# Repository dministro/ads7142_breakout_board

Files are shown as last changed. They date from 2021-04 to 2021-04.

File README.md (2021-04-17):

# ADS7142 breakout board (A003.0000017200_DM.ADS7142.BOB)

This is a simple breakout board for
 Texas Instruments ADS7142 (X2QFN) dual-channel, programmable sensor monitor.

[0] - Datasheet: https://www.ti.com/lit/ds/symlink/ads7142.pdf

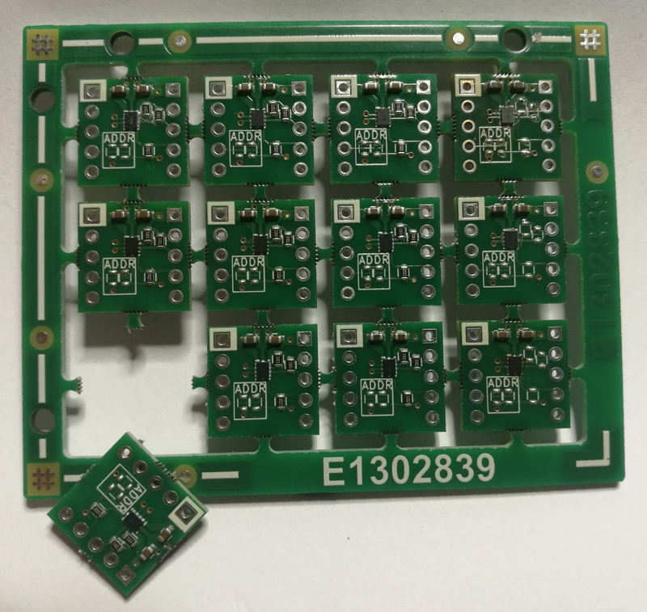
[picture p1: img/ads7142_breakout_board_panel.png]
ADS7142 breakout board


## Pinout

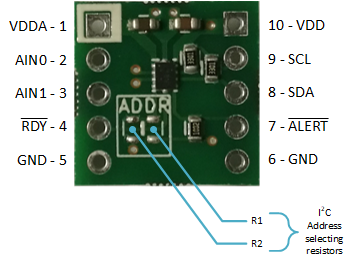
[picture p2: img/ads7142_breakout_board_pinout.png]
ADS7142 breakout board pinout


|# |Function  |Description |
|-----|---|---|
|1 |VDDA |Analog supply input. See AVDD in ref [0] |
|2 |AIN0 |Channel 0 analog signal input, or positive analog signal input. See AINP/AIN0 in ref [0] |
|3 |AIN1 |Channel 1 analog signal input, or negative analog signal input. See AINM/AIN1 in ref [0] |
|4 |RDY |See BUSY/RDY in ref [0] |
|5 |GND |Ground for power supply |
|6 |GND |Ground for power supply |
|7 |ALERT |See ALERT in ref [0] |
|8 |SDA |Serial data in/out. See SDA in ref [0] |
|9 |SCL |Serial clock. See SCL in ref [0] |
|10 |VDD |Digital I/O supply voltage. See DVDD in ref [0]  |

## Configuration

To select the device address on I2C bus, populate the proper resistor values (R1, R2) as described in the datasheet. See chapter *7.3.6 I2C Address Selector* in [0]

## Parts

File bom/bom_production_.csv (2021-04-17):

Component | Description | Part | References | Value | Footprint | Quantity Per PCB | Manufacturer | PartNumber | Distributor#1 | OrderingCode#1 | Distributor#2 | OrderingCode#2 | InsertManufacturer | InsertProductCode | InsertDistributor#1 | InsertOrderingCode#1 | MateManufacturer | MateProductCode | MateDistributor#1 | MateOrderingCode#1 | ExtraTool#1Manufacturer | ExtraTool#1ProductCode | ExtraTool#1Distributor#1 | ExtraTool#1OrderingCode#1 | Datasheet | Layer
1 | Unpolarized capacitor | C | C1003 C1004 | 1u / X7R / 16V | C_0603 | 2 | KEMET | C0603C105K4RACTU | www.mouser.com | 80-C0603C105K4R |  |  |  |  |  |  |  |  |  |  |  |  |  |  | ~ | F.Cu
2 | Unpolarized capacitor | C | C1001 C1002 | 470p / X7R / 16V | C_0402 | 2 | KEMET | C0402C471K4RACTU | www.mouser.com | 80-C0402C471K4R |  |  |  |  |  |  |  |  |  |  |  |  |  |  | ~ | B.Cu
3 | Generic connector, single row, 01x05, script generated (kicad-library-utils/schlib/autogen/connector/) | Conn_01x05_Male | J1001 J1002 | Conn_01x05_Male | Pin_Header_Straight_1x05_Pitch2.54mm | 2 | Amphenol FCI | 77311-118-05LF | www.mouser.com | 649-77311-118-05LF |  |  |  |  |  |  |  |  |  |  |  |  |  |  | ~ | B.Cu
4 | Resistor | R | R1005 | 10k / 1% | R_0603 | 1 | Vishay / Dale | CRCW060310K0FKEAC | www.mouser.com | 71-CRCW060310K0FKEAC |  |  |  |  |  |  |  |  |  |  |  |  |  |  | ~ | F.Cu
5 | Resistor | R | R1001 R1002 | 1k / 1% | R_0402 | 2 | Vishay / Dale | CRCW04021K00FKEDC | www.mouser.com | 71-CRCW04021K00FKEDC |  |  |  |  |  |  |  |  |  |  |  |  |  |  | ~ | B.Cu
6 | Resistor | R | R1003 R1004 | 3.3k / 1% | R_0603 | 2 | Vishay / Dale | CRCW06033K30FKEAC | www.mouser.com | 71-CRCW06033K30FKEAC |  |  |  |  |  |  |  |  |  |  |  |  |  |  | ~ | F.Cu
7 | Resistor | R | R1006 R1007 | DNP | R_0603 | 2 |  |  |  |  |  |  |  |  |  |  |  |  |  |  |  |  |  |  | ~ | F.Cu
8 | Nanopower, Dual-Channel, Programmable Sensor Monitor | ADS7142 | U1001 | ADS7142 | Texas_RUG0010A_X2QFN-10_1.5x2mm_Pitch0.5mm | 1 | Texas Instruments | ADS7142IRUGT | www.mouser.com | 595-ADS7142IRUGT |  |  |  |  |  |  |  |  |  |  |  |  |  |  | https://www.ti.com/lit/ds/symlink/ads7142.pdf | F.Cu
Component Groups: | 8
Component Count: | 14
Fitted Components: | 14
Number of PCBs: | 1
Total components: | 14
Schematic Version:
Schematic Date:
BoM Date: | 17/04/2021 10:51:19
Schematic Source: | D:\Projects\DM.ADS7142.BOB\cad\eda\A003.0000017200_DM.ADS7142.BOB\A003.0000017200_DM.ADS7142.BOB.sch
KiCad Version: | Eeschema (5.1.6-14-g3ac0951e1-dirty)

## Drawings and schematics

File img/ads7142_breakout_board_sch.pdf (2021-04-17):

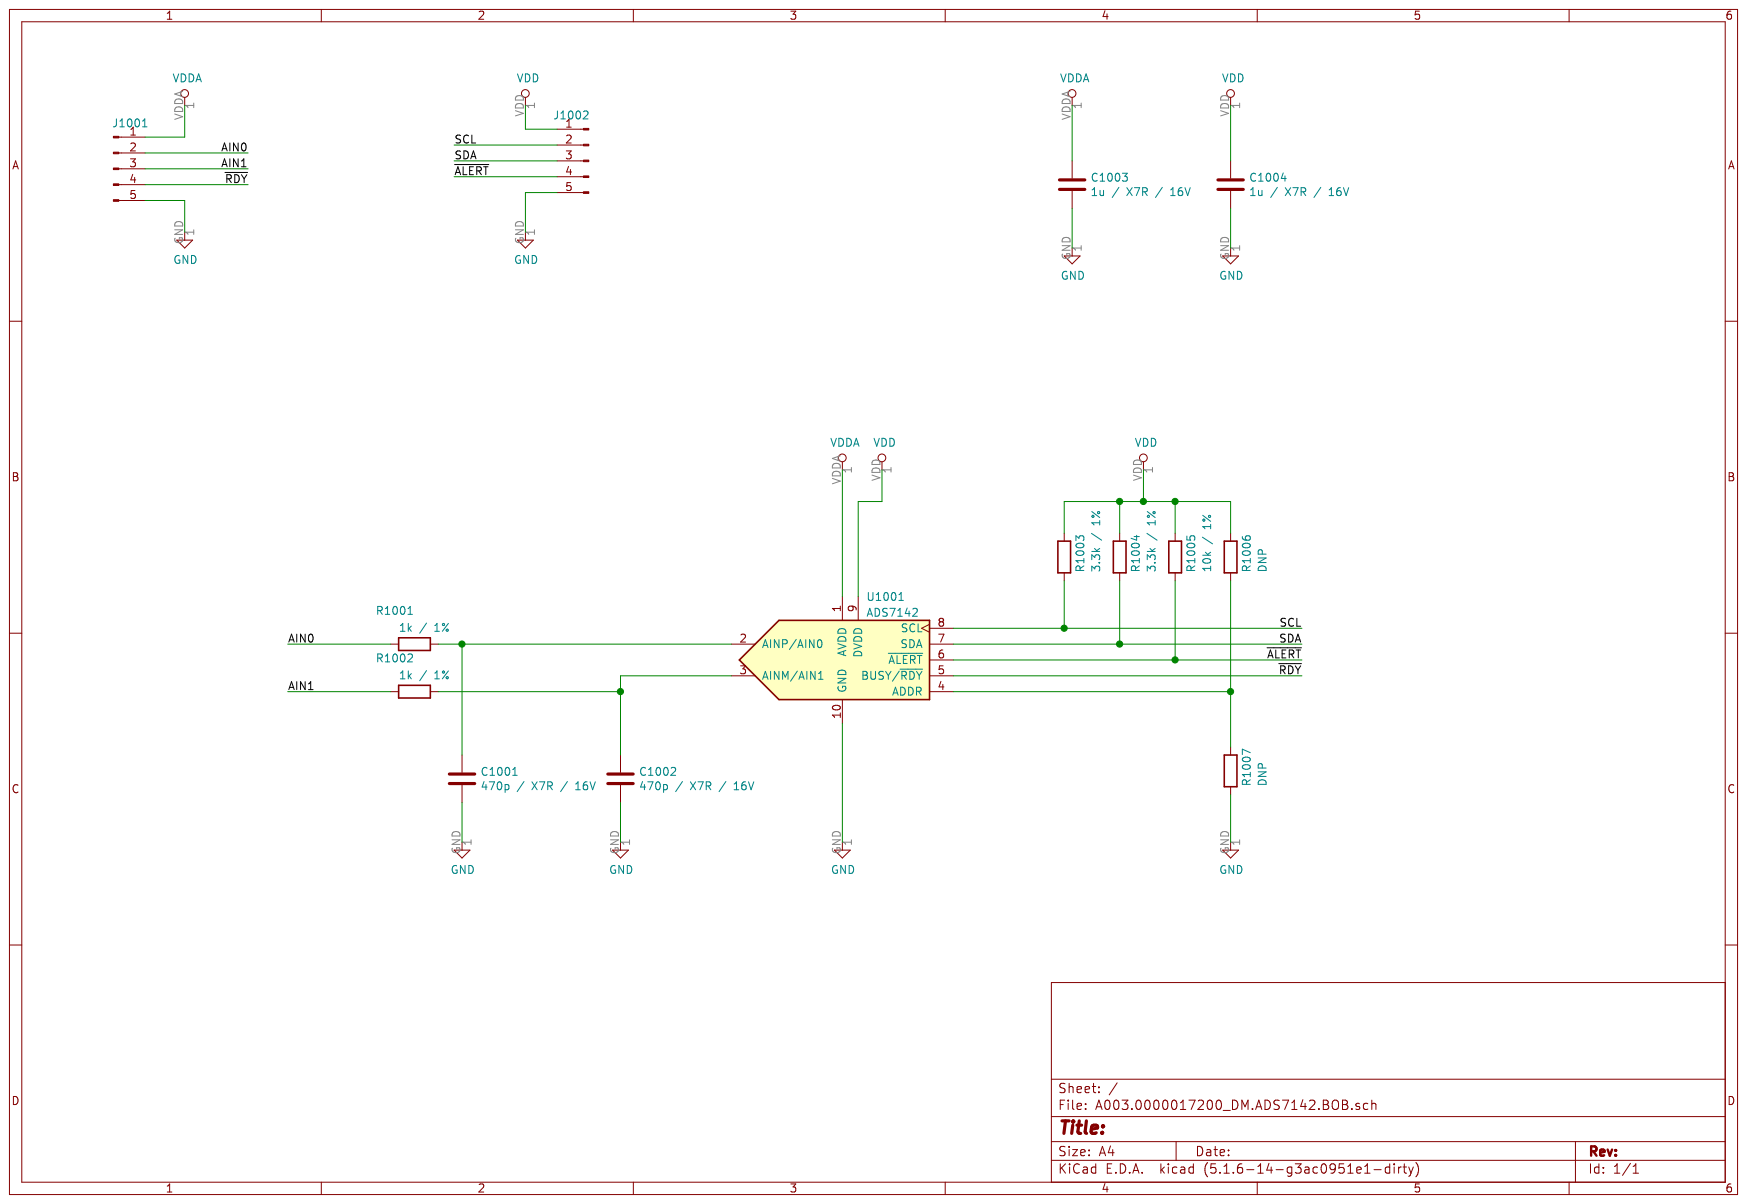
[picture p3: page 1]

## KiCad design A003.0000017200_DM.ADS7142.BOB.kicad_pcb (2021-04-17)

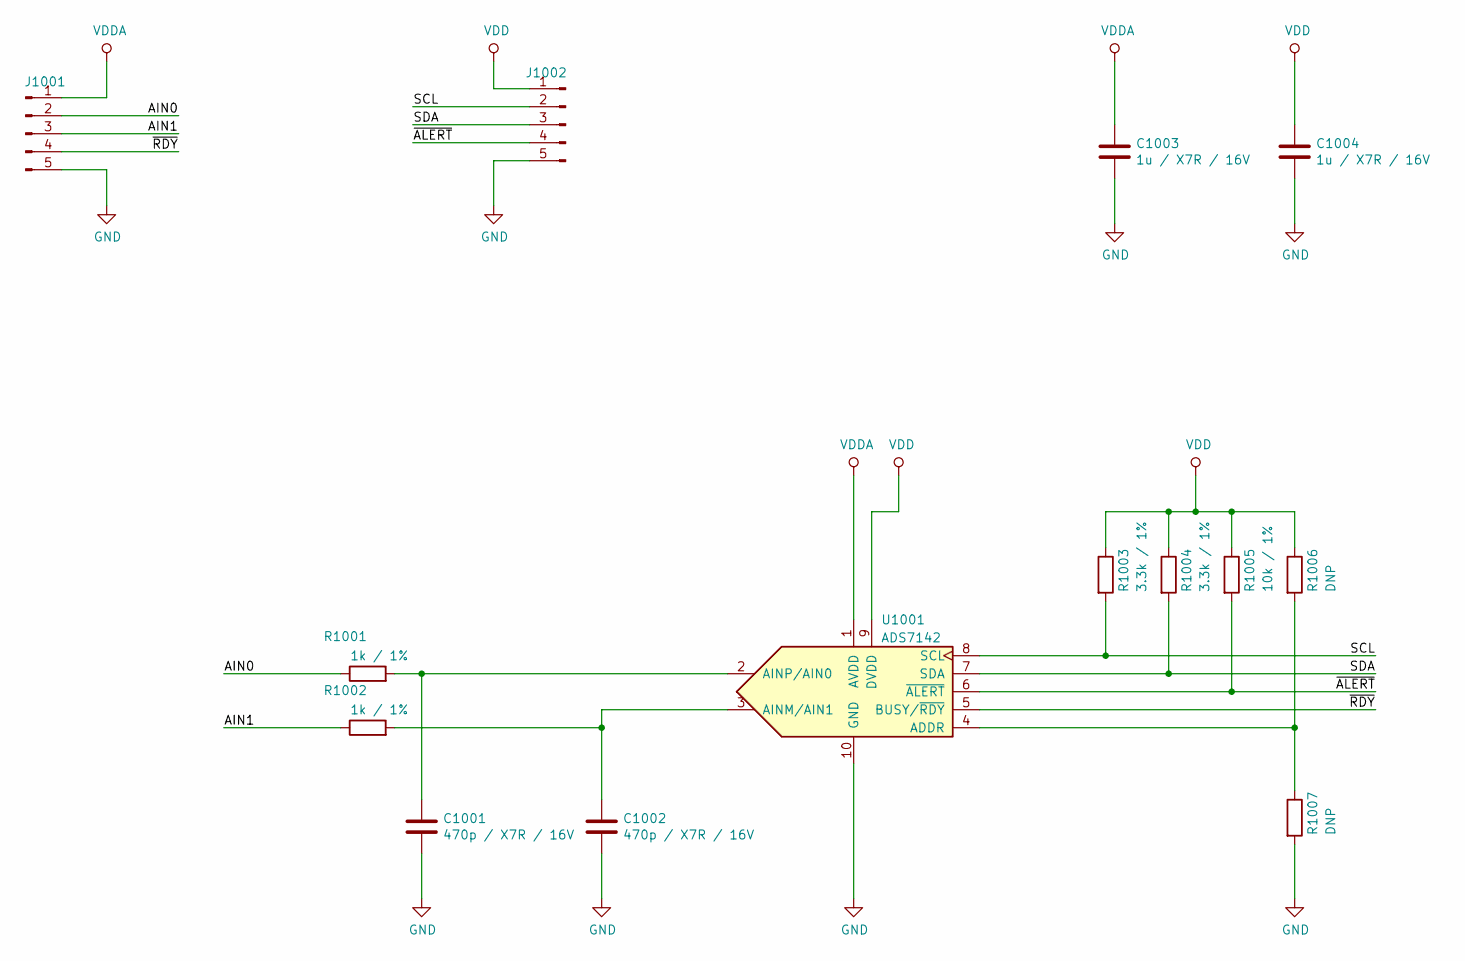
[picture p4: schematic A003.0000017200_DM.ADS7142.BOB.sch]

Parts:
C1001, C1002: 470p / X7R / 16V; C_0402; PartNumber C0402C471K4RACTU
C1003, C1004: 1u / X7R / 16V; C_0603; PartNumber C0603C105K4RACTU
J1001, J1002: Conn_01x05_Male; Pin_Header_Straight_1x05_Pitch2.54mm; PartNumber 77311-118-05LF
R1001, R1002: 1k / 1%; R_0402; PartNumber CRCW04021K00FKEDC
R1003, R1004: 3.3k / 1%; R_0603; PartNumber CRCW06033K30FKEAC
R1005: 10k / 1%; R_0603; PartNumber CRCW060310K0FKEAC
R1006, R1007: DNP; R_0603
U1001: ADS7142; Texas_RUG0010A_X2QFN-10_1.5x2mm_Pitch0.5mm; PartNumber ADS7142IRUGT

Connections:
/AIN0: J1001.2, R1001.1
/AIN1: J1001.3, R1002.1
/SCL: J1002.2, R1003.2, U1001.8 (SCL)
/SDA: J1002.3, R1004.2, U1001.7 (SDA)
/~ALERT: J1002.4, R1005.2, U1001.6 (~ALERT)
/~RDY: J1001.4, U1001.5 (BUSY/~RDY)
GND: C1001.2, C1002.2, C1003.2, C1004.2, J1001.5, J1002.5, R1007.2, U1001.10 (GND)
unnamed: C1001.1, R1001.2, U1001.2 (AINP/AIN0)
unnamed: C1002.1, R1002.2, U1001.3 (AINM/AIN1)
unnamed: R1006.2, R1007.1, U1001.4 (ADDR)
VDD: C1004.1, J1002.1, R1003.1, R1004.1, R1005.1, R1006.1, U1001.9 (DVDD)
VDDA: C1003.1, J1001.1, U1001.1 (AVDD)

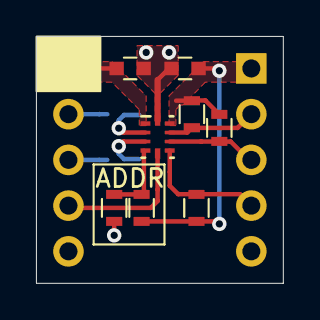
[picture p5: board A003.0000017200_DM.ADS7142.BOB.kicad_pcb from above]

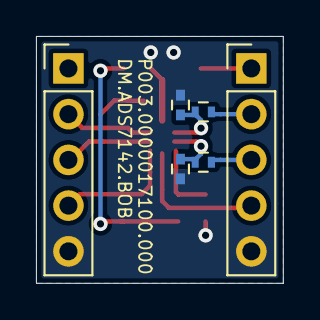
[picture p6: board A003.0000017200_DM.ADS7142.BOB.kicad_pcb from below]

Board: 2 copper layers, 13.7 x 13.7 mm, 14 parts (6 on the bottom side), 12 nets.
